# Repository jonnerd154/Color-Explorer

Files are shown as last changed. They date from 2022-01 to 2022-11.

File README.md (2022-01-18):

# Color-Explorer
A simple PCB to allow students to explore colors and mixing colors of light.

The board provides three slider potentiometers which each control the brightness of one color of light. There are four RGB LEDs. The first three show the individual color component as configured by the position of the sliders - one red, one blue, and one green. The fourth LED shows the mixed/combined colors. A jumper can be removed to disable the "mixed" LED, allowing students to set their sliders and make a hypothesis about what color will result from the mix. After recording their hypothesis, the jumper can be reinstalled to reveal the correct answer.

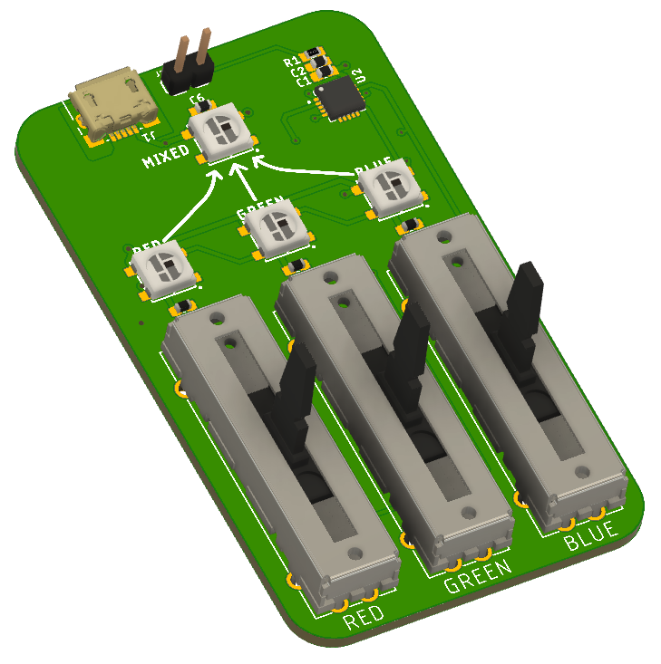
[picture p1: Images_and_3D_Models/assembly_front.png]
FrontImage


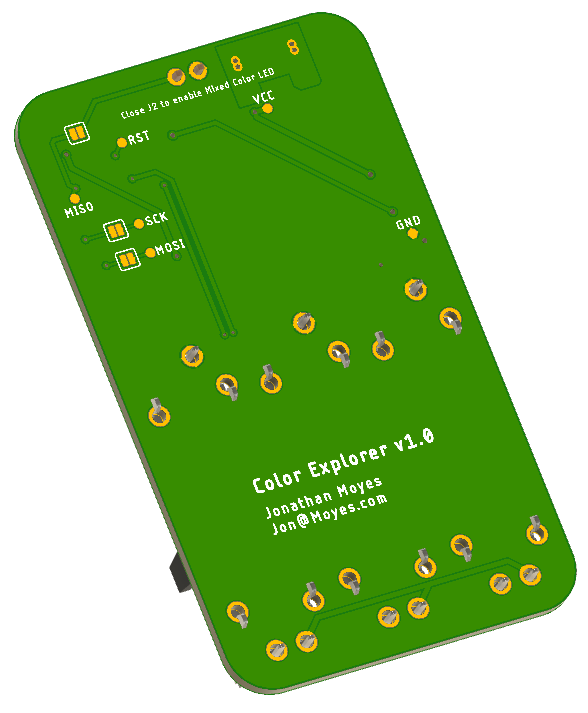
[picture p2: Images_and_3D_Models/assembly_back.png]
BackImage


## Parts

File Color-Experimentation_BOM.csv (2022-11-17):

Qty | Value | Device | Package | Parts | Description | DESCRIPTION | DIGI-KEY_PART_NUMBER | MF | MFG | MP | MPN | PACKAGE | PURCHASE-URL | VALUE
1 |  | CONN_02 | 1X02 | J2 | 0.1 Header - 2 pin, 1 row" |  |  |  | Amazon.com |  | B07PWZ6G9G
5 | 0.1uF | CAP_0.1UF_25V_X7R-0603 | CAP_0603 | C1, C3, C4, C5, C6 | 0.1µF ±10% 25V Ceramic Capacitor X7R |  |  |  | Samsung Electro-Mechanics |  | CL10B104KA8WPNC |  |  | 0.1uF
1 | 10118193-0001LF | 10118193-0001LF | CONN_10118193-0001LF_AMP | J1 |  |  |  |  | Amphenol ICC |  | 10118193-0001LF
3 | 10k | PTA2043-2015DPB103 | POT_PTA2043 | BLUE_POT, GREEN_POT, RED_POT | 10 kOhms 0.1W, 1/10W Through Hole Slide Potentiometer Top Adjustment Type |  |  |  | Bourns Inc. |  | PTA2043-2015DPB103 |  |  | 10k
1 | 10k | RES_10K_1%R0603 | R0603 | R1 | 10 kOhms ±1% 0.1W, 1/10W Chip Resistor 0603 (1608 Metric) Thick Film |  |  |  | Yageo |  | RC0603FR-0710KL |  |  | 10k
1 | 22uF | CAP_22UF_16V_X5R-0603 | C0603 | C2 | 22µF ±20% 16V Ceramic Capacitor X5R 0805 (2012 Metric) |  |  |  | Samsung Electro-Mechanics |  | CL21A226MOQNNNE |  |  | 22uF
1 | ATTINY85-20SU | ATTINY85-20SU | SOIC127P798X216-8N | U3 | AVR AVR® ATtiny, Functional Safety (FuSa) Microcontroller IC 8-Bit 20MHz 8KB (4K x 16) FLASH 8-SOIC | AVR AVR® ATtiny, Functional Safety (FuSa) Microcontroller IC 8-Bit 20MHz 8KB (4K x 16) FLASH 8-SOIC | ATTINY85-20SU-ND | Microchip |  | ATTINY85-20SU |  | SOIC-8 Microchip | https://pricing.snapeda.com/search/part/ATTINY85-20SU/?ref=eda
1 | JUMPER-SMT_2_NO_SILK | JUMPER-SMT_2_NO_SILK | SMT-JUMPER_2_NO_SILK | JP3 | Normally Open solder jumper
4 | WS2812 | WS2812_5050 | WS2812-5X5-4PIN | BLUE, GREEN, MIXED, RED | Addressable RGB LED - 1 Wire |  |  |  | SparkFun.com |  | WS2812B 5050 |  |  | WS2812

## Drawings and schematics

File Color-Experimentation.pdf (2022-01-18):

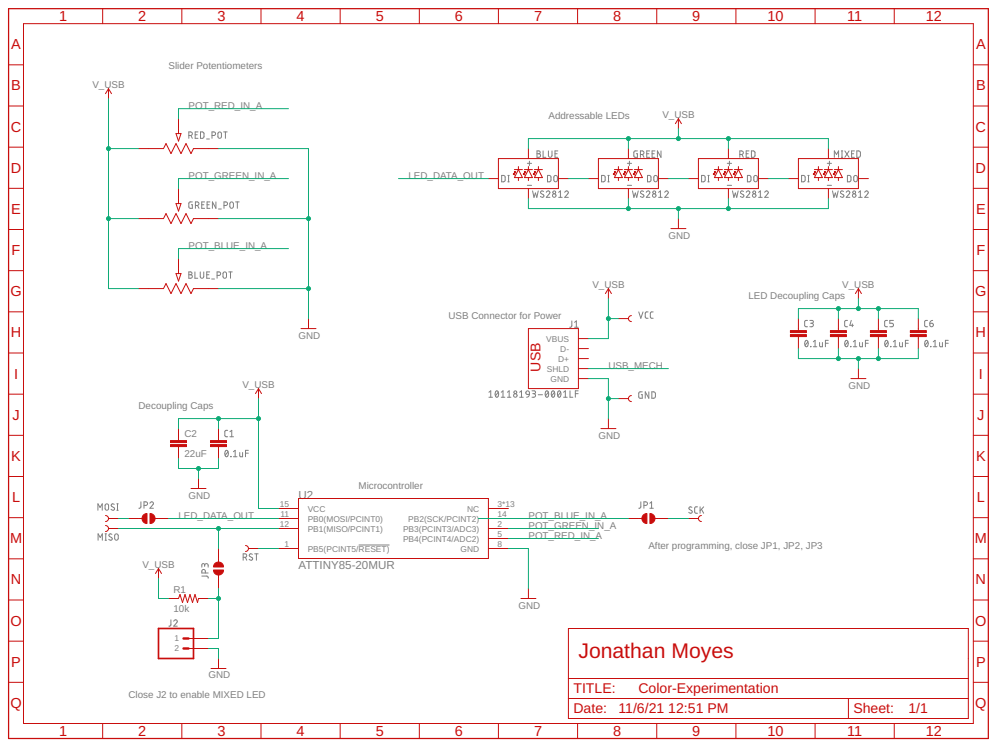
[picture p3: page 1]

Addressable LEDs Slider Potentiometers

LED Decoupling Caps USB Connector for Power

Close J2 to enable MIXED LED

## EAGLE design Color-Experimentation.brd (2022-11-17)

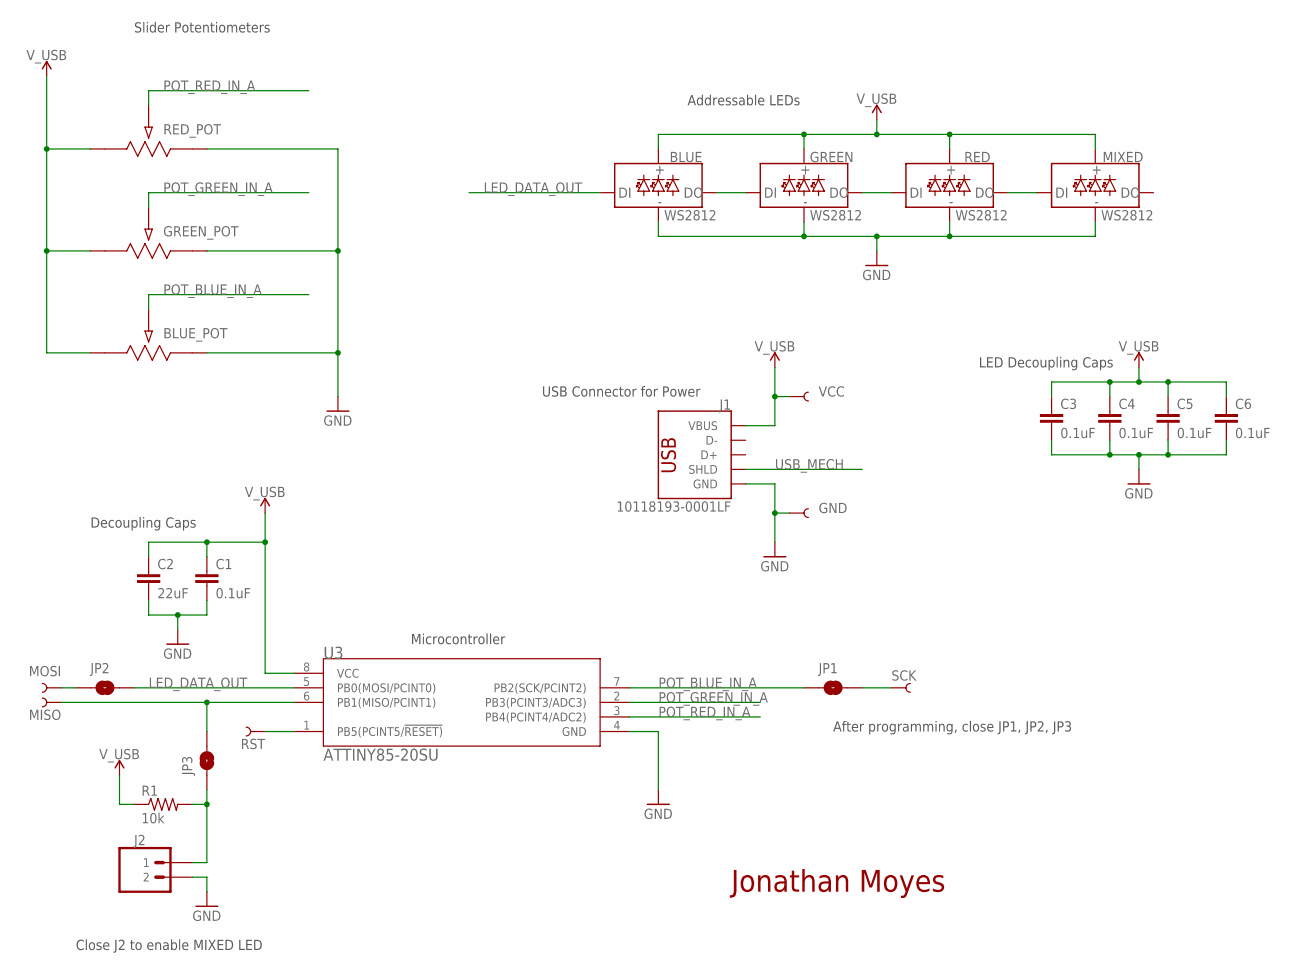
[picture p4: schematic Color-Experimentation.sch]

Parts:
BLUE: WS2812; WS2812-5X5-4PIN
BLUE_POT: 10k; POT_PTA2043
C1, C3, C4, C5, C6: 0.1uF; CAP_0603
C2: 22uF; C0603
GND: TEST-POINT40MIL; TESTPOINT_40MIL_ROUND
GREEN: WS2812; WS2812-5X5-4PIN
GREEN_POT: 10k; POT_PTA2043
J1: 10118193-0001LF; CONN_10118193-0001LF_AMP
J2: CONN_02; 1X02
JP1, JP2, JP3: JUMPER-SMT_2_NO_SILK; SMT-JUMPER_2_NO_SILK
MISO: TEST-POINT40MIL; TESTPOINT_40MIL_ROUND
MIXED: WS2812; WS2812-5X5-4PIN
MOSI: TEST-POINT40MIL; TESTPOINT_40MIL_ROUND
R1: 10k; R0603
RED: WS2812; WS2812-5X5-4PIN
RED_POT: 10k; POT_PTA2043
RST: TEST-POINT40MIL; TESTPOINT_40MIL_ROUND
SCK: TEST-POINT40MIL; TESTPOINT_40MIL_ROUND
U3: ATTINY85-20SU; SOIC127P798X216-8N
VCC: TEST-POINT40MIL; TESTPOINT_40MIL_ROUND

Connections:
GND: BLUE.GND, BLUE_POT.3, C1.2, C2.2, C3.2, C4.2, C5.2, C6.2, GND.P$1, GREEN.GND, GREEN_POT.3, J1.5 (GND), J2.1 (2), MIXED.GND, RED.GND, RED_POT.3, U3.4 (GND)
LED_DATA_OUT: BLUE.DI, JP2.2, U3.5 (PB0(MOSI/PCINT0))
MOSI: JP2.1, MOSI.P$1
unnamed: BLUE.DO, GREEN.DI
unnamed: GREEN.DO, RED.DI
unnamed: J2.2 (1), JP3.1, R1.2
unnamed: RST.P$1, U3.1 (PB5(PCINT5/!RESET))
unnamed: MIXED.DI, RED.DO
unnamed: JP3.2, MISO.P$1, U3.6 (PB1(MISO/PCINT1))
POT_BLUE_IN_A: BLUE_POT.WIPER (2), JP1.1, U3.7 (PB2(SCK/PCINT2))
POT_GREEN_IN_A: GREEN_POT.WIPER (2), U3.2 (PB3(PCINT3/ADC3))
POT_RED_IN_A: RED_POT.WIPER (2), U3.3 (PB4(PCINT4/ADC2))
SCK: JP1.2, SCK.P$1
USB_MECH: J1.4 (SHLD), J1.6 (SHLD), J1.7 (SHLD), J1.8 (SHLD), J1.9 (SHLD), J1.S_1 (SHLD), J1.S_1_H1 (SHLD), J1.S_1_H2 (SHLD), J1.S_2 (SHLD), J1.S_2_H1 (SHLD), J1.S_2_H2 (SHLD)
V_USB: BLUE.VCC, BLUE_POT.1, C1.1, C2.1, C3.1, C4.1, C5.1, C6.1, GREEN.VCC, GREEN_POT.1, J1.1 (VBUS), MIXED.VCC, R1.1, RED.VCC, RED_POT.1, U3.8 (VCC), VCC.P$1

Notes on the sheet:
Decoupling Caps
After programming, close JP1, JP2, JP3
LED Decoupling Caps
USB Connector for Power
Addressable LEDs
Slider Potentiometers
Microcontroller
Close J2 to enable MIXED LED
Jonathan Moyes

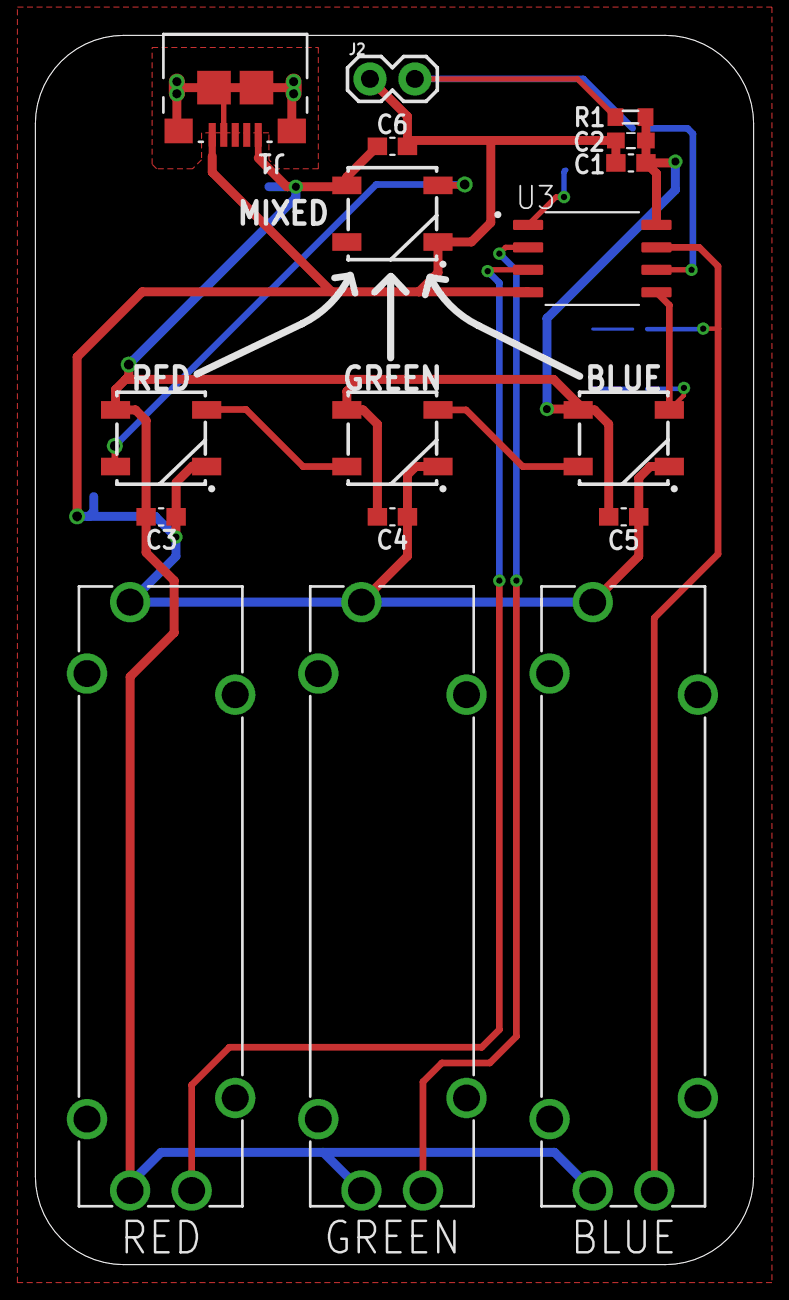
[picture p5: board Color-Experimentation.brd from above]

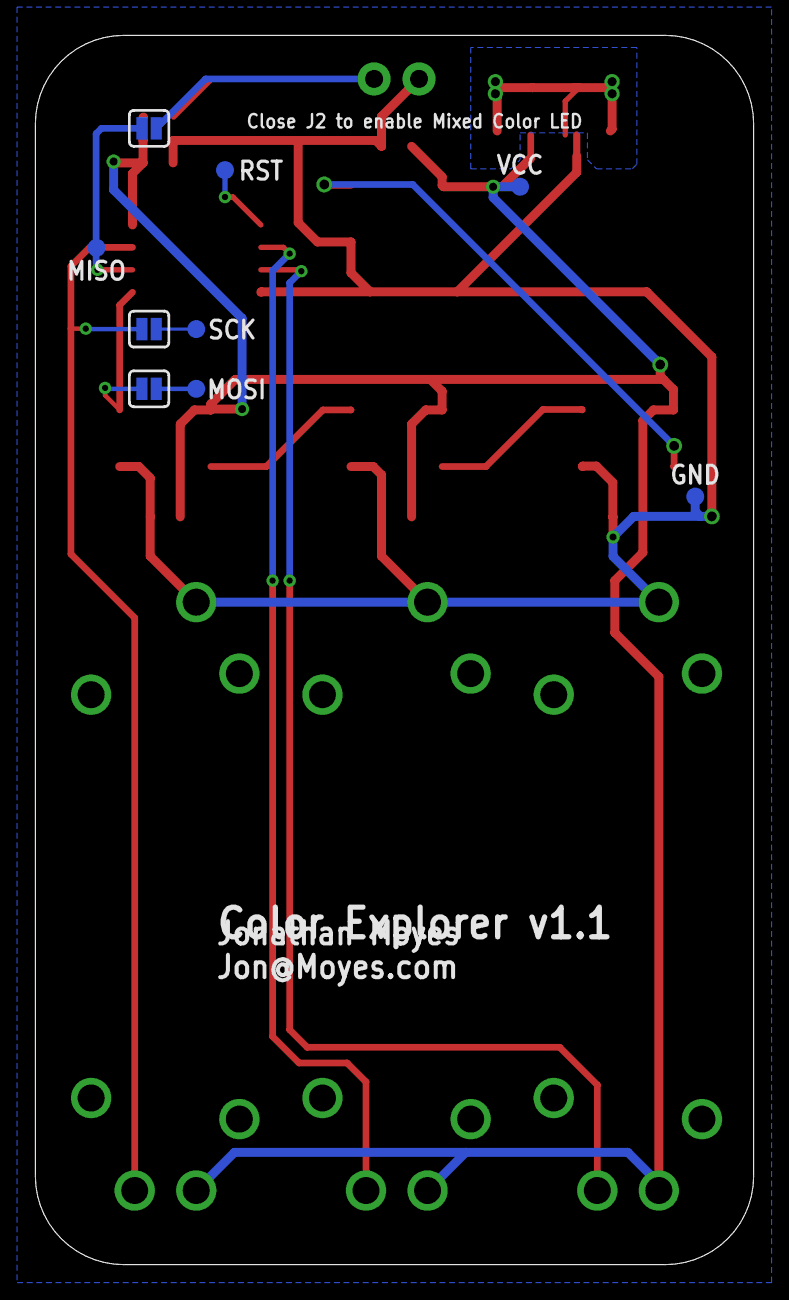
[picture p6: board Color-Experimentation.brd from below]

Board: 2 copper layers, 40.6 x 69.5 mm, 26 parts (9 on the bottom side), 15 nets.

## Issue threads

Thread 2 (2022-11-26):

v1.1 Bugs

jonnerd154, 2022-11-26:
- [ ] Slider Pot footprint incorrect: mech pins reversed L/R. Electrical pins are okay.
- [ ] Slider Pots upside down: fixed iin firmware
- [ ] USB Connector too far from PCB edge: mech interference
- [ ] R1, C1, C2 too close together
- [ ] Solder jumpers in wrong place: need pogopins to remain connected, but disconnect non-ICSP peripherals
- [ ] Can we support both the QFN and SOIC packages simultaneously with overlapping footprints?

jonnerd154, 2022-11-26:
Also consider adding 3x AAA batteries as an option. USB can remain as optional source. Add "power multiplexer" with P-FET and a schottky to prevent charging/back-powering if two sources are connected simultaneously.

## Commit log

2021-11-06 Cleanup schematic and routing
    [Color-Experimentation.brd, Color-Experimentation.sch]
2021-11-06 Use LBR, cleanup, export Bill of Materials
    [Color-Experimentation.brd, Color-Experimentation.sch, Color-Experimentation_BOM.csv]
2021-11-06 Add pullup, solder jumper on "mixed LED enable"
    [Color-Experimentation.brd, Color-Experimentation.sch, Color-Experimentation_BOM.csv]
2021-11-06 Move corner of board to 0,0
    [Color-Experimentation.brd]
2021-11-06 add attribution to sch
    [Color-Experimentation.sch]
2021-11-06 Schematic to PDF
2021-11-06 add CAM file, include t/bNames in silkscreen
2021-11-08 add 3d models, fusion push
    [Color-Experimentation.brd, Color-Experimentation.sch]
2022-01-18 Add assembly images & stepfile
2022-11-17 Switch microcontroller for availability: v1.1
    [Color-Experimentation.brd, Color-Experimentation.sch, Color-Experimentation_BOM.csv]
